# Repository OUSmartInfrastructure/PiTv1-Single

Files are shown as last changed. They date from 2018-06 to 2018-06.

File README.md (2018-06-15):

# PiTv1-Single
Pi Temperature (PiT) Sensor Single Sensor v1.0

PiT v1 is an attempt to create Raspberry Pi based SNMP datacenter temperature/humidity/pressure sensors. An attempt to use cost-effective prodcuts was a priority.

Instructions/diagrams/tutorial is provided to get users started.

Special thanks to all the ITS students and faculty that helped made this possible and Adafruit for the great sensors and tutorials.

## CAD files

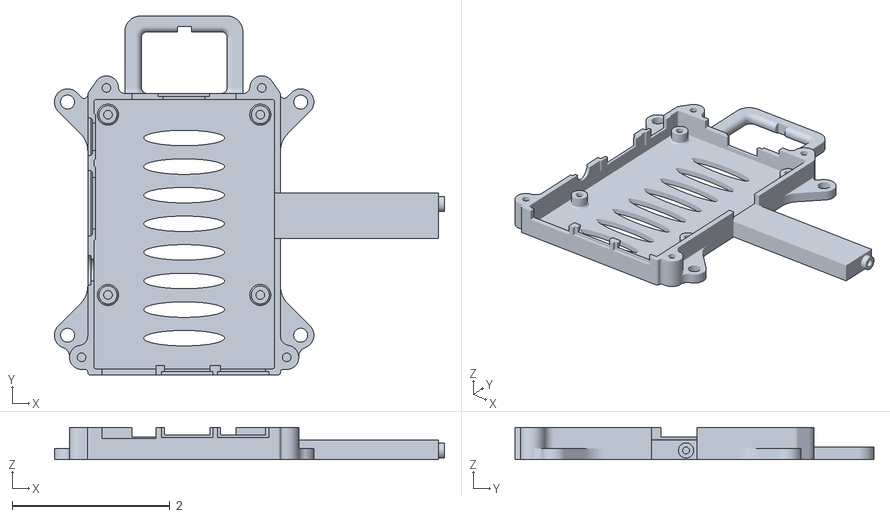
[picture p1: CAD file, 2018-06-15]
PiT-Case_Bottom.stl
4.94 x 4.55 x 0.406

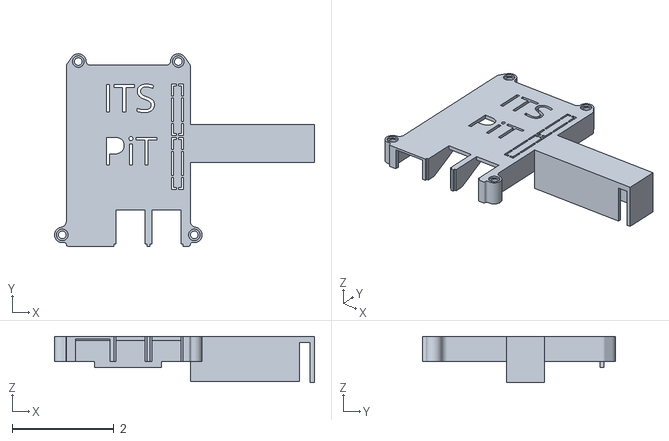
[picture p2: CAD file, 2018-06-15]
PiT-Case_Top.stl
5.12 x 3.79 x 0.909

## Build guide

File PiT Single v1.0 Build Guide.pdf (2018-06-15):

### PiT Single v1.0 Assembly and Configuration Guide

Documentation v1.1
Overview:
This guide will walk you through the steps needed to assemble and configure your very own PiT unit. PiT stands for ‘Pi Temperature Sensor’, but can be expanded to do more than just measure temperature. At its core, a PiT is just a Raspberry Pi with sensors attached to it that can be polled using SNMP.

What You’ll Need:
- PiT Case File (https://cad.onshape.com/documents/9fd48c46746b4ed2ba58fd89/w/bc32df8f708adf12e78a438a/e/d429803c952da15bd93a3a67)
- Raspberry Pi 3
- Rasbian OS Image

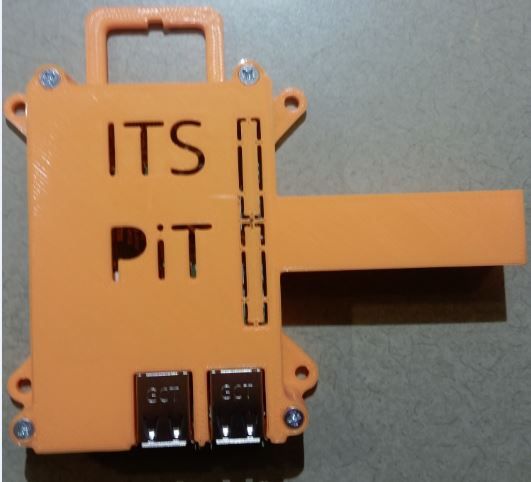
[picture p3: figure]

- 2.5 x 8 mm screw to attach sensor to case.

Adafruit Sensor Wiring Guide

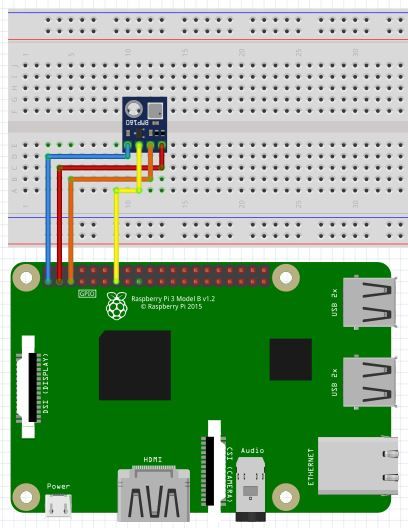
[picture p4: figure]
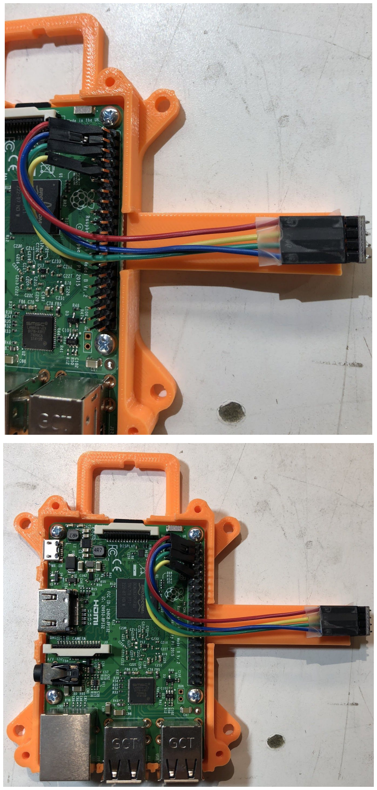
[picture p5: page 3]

Chinese Sensor Wiring Guide Configuring the PiT

= Executable commands

= Additional Info

Updating and Upgrading
***Some SD cards get corrupted on an Update/Upgrade depending on manufacturer and/or speed
After assembling and powering on your PiT unit, updating and upgrading the Rasbian OS running on the Pi is recommended.

sudo apt-get update && apt-get dist-upgrade

Enabling I2C
I2C allows the sensors connected to the PiT unit to talk back to the Raspberry Pi. This will need to be enabled on the PiT unit. Connect to the PiT console (SSH/Monitor+Keyboard) and enable I2C on the Raspberry Pi.

sudo raspi-config
Interfacing Options > I2C > Enable

Installing Packages
There are a few packages that need to be installed for your PiT Unit to operate properly.

sudo apt-get --yes install i2c-tools python-smbus snmpd snmp sshpass

Sensor Detection
Test to see if the temperature sensor is being detected by I2C. The Chinese Temperature Sensors will show as a 76 while the Adafruit Temperature Sensors will show a 77.

i2cdetect -y 1

I2C Access
Allow the snmp user access to I2C.

sudo adduser snmp i2c

PiT Directory and Files

Adafruit_BME280.py | Initializes sensor and provides code for pulling values from it. Referenced by other scripts.
cpu-temp.sh | Pulls system CPU Temperature
snmp-baro-c.sh | snmp-baeo-c.py | Pulls barometric pressure
snmp-humd-c.sh | snmp-humd-c.py snmp-humd-a.sh | snmp-humd-a.py | Pulls humidity
snmp-temp-c.sh | snmp-temp-c.py snmp-temp-a.sh | snmp-temp-a.py | Pulls temperature
tempOffset.txt | Allows user to set a temperature offset to “calibrate” sensors
C = Chinese Sensor | A = Adafruit Sensor

Now we need to setup the PiT Directory (/usr/local/bin/PiT), this is where almost all PiT related activities take place on the backend. We also change ownership of /bin/ and /bin/PiT/ to the pi user.

sudo mkdir /usr/local/bin/PiT

sudo chown pi /usr/local/bin
sudo chown pi /usr/local/bin/PiT

Now that we have the PiT directory created with the proper ownership, we need to unpack the PiT TAR file into the newly created PiT Directory. This will place all the necessary backend scripts onto your PiT Unit.

PiT TAR File (https://www.evernote.com/shard/s37/res/e6bd926c-9348-4763-a06e-fbafe5c381aa/2017-06-20-bin.tar.gz) ***This is out-of-date!

sudo tar -zxvf [Insert PiT TAR File Name] -C /usr/local/bin/PiT

We now need to make the system see the scripts we just moved into the PiT Directory as executables.

sudo chmod u+x /usr/local/bin/PiT/*.sh
sudo chmod u+x /usr/local/bin/PiT/*.py

Next, we need to install the necessary pre-compiled Python scripts.

Python Scripts (https://www.evernote.com/shard/s37/res/72ecd69f-7037-436d-8460-67c875375aa5/2017-06-20-egg.tar.gz)

sudo tar -zxvf 2017-06-20-egg.tar.gz -C /usr/local/lib/python2.7/dist-packages

Testing PiT Scripts
After setting up the PiT Directory and installing the appropriate components, we should test the PiT Scripts directly to ensure they work before we point SNMPD to them. They should all return a decimal value if operating appropriately.

Chinese Sensor:
sudo python /usr/local/bin/PiT/snmp-temp-c.py 0x76
sudo python /usr/local/bin/PiT/snmp-humd-c.py 0x76 sudo python /usr/local/bin/PiT/snmp-baro-c.py 0x76

Adafruit Sensor:
sudo python /usr/local/bin/PiT/snmp-temp-a.py 0x77
sudo python /usr/local/bin/PiT/snmp-humd-a.py 0x77

Configure SNMPD for PiT Scripts
We now need to configure SNMPD to call our PiT Scripts when a SNMPD call is made to a particular OID. Open up the SNMPD configuration file.

sudo nano /etc/snmp/snmpd.conf

The following line needs to be commented out:
agentAddress udp:127.0.0.1:161 (Add a # in front of this line) Add this line following the one you just commented out:
agentAddress udp:161
Find the following line:
#rocommunity public localhost

Add this line below it:
rocommunity public
Find the following line:
# "Pass-through" MIB extension command

Add this line below it:
pass .1.3.6.1.2.1.25.1.20 /bin/sh /usr/local/bin/cpu-temp.sh

Add these lines as well DEPENDING ON WHAT SENSOR YOU’RE USING!:

(Adafruit Sensor)
pass .1.3.6.1.2.1.25.1.8 /bin/sh /usr/local/bin/PiT/snmp-temp-a.sh pass .1.3.6.1.2.1.25.1.9 /bin/sh /usr/local/bin/PiT/snmp-humd-a.sh

(Chinese Sensor)
pass .1.3.6.1.2.1.25.1.8 /bin/sh /usr/local/bin/PiT/snmp-temp-c.sh pass .1.3.6.1.2.1.25.1.9 /bin/sh /usr/local/bin/PiT/snmp-humd-c.sh pass .1.3.6.1.2.1.25.1.10 /bin/sh /usr/local/bin/PiT/snmp-baro-c.sh

With all the appropriate changes made to the SNMPD config, we need to restart the snmpd daemon.

sudo service snmpd restart

Testing SNMPD
Now we need to test SNMP to ensure it is using the PiT Scripts and returning values appropriately.

snmpget -v2c -cpublic localhost .1.3.6.1.2.1.25.1.8
snmpget -v2c -cpublic localhost .1.3.6.1.2.1.25.1.9
snmpget -v2c -cpublic localhost .1.3.6.1.2.1.25.1.10

Remote PiT Upgrades

Overview
A number of bash scripts and additional files have been created to simplify the upgrading of multiple PiT Units when changes are made or additional scripts are added. As with everything else, these scripts live in the /usr/local/bin/PiT/ directory.
IPs.txt | Text file used to store the IPs of all PiT Units to be upgraded. Each IP should be on its own line. Referenced by the pre-remoteUpgrade.sh and remoteUpgrade.sh scripts.
pre-remoteUpgrade.sh | Used to obtain the SSH keys of all the hosts in the IPs.txt file. User will need to manually type “Yes” for each host. The remoteUpgrade.sh script will fail if you do not have all the necessary SSH keys already installed on the PiT that is pushing the upgrade.
remoteUpgrade.sh | 1.) Creates TAR of /PiT/ directory along with a copy of the snmpd.conf 2.) Pushes TAR to remote PiTs, recreates /PiT/ directory, and overwrites snmpd.conf with the updated version Does not affect tempOffset.txt on remote PiT Units.
